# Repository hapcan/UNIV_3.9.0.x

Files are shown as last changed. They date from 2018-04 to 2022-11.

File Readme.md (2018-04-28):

UNIV 3.9.0.x
============

OPEN COLLECTOR OUTPUTS - Isolated 10 channel NPN open collector outputs with clamp diodes, 24V, 500mA per channel

Device webpage: http://hapcan.com/devices/universal/univ_3/univ_3-9-0-x/

Hardware created in Eagle PCB Software http://www.cadsoftusa.com/

Firmware created in Microchip MPLAB http://www.microchip.com/mplabide/ in assembly language

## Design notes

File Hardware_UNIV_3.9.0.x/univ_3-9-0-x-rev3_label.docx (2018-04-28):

ISOLATED OPEN

COLLECTOR OUTPUTS

10 CHANNEL
UOCMAX = 24V | | IOCMAX = 500mA
TYPE | UNIV 3.9.0.x
S/N | 00000678h
BUS BUS | hapcan.com

IZOLOWANE WYJŚCIA

OTWARTY KOLEKTOR

10 KANAŁÓW
UOCMAX = 24V | | IOCMAX = 500mA
TYP | UNIV 3.9.0.x
S/N | 00000678h
BUS BUS | hapcan.com

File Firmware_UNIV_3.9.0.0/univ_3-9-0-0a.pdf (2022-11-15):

## OPEN COLLECTOR OUTPUTS FIRMWARE

# UNIV 3.9.0.0

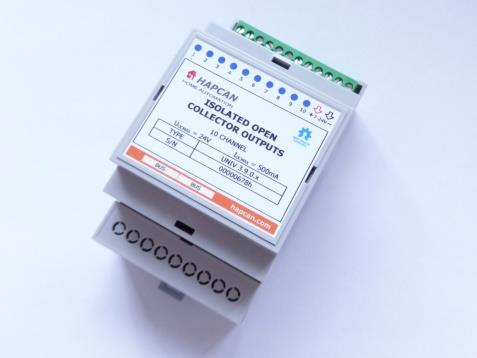
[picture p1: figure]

© 2018 hapcan.com | univ_3-9-0-0a.pdf - page 1 / 6

### 1. Features

- Firmware for 10 open collector outputs module
- 3 control instructions (on, off, toggle)
- 3 blocking instructions
- 10 timers (1 for each output) for instruction execution delay 1s-24h
- Allows defining up to 128 CAN messages which can indirectly control the module
- Settable output power up state
- Uptime counter
- Health check monitor
- Transmit (42 messages) and receive (42 messages) FIFO buffers

### 2. Compatibility

- Firmware for UNIV 3.9.0.x module
- Firmware can be uploaded into processor with bootloader version 3.1 or compatible.

### 3. Firmware version

UNIV | 3 | . | 9 | . | 0 | . | 0
firmware version
application version
application (open collector outputs) processor version
universal processor

### 4. Communication Frames (messages)

### 4.1. Open collector output message

The module sends one message to the bus for each channel as soon as the status of one of the outputs changes. The following table shows the meaning of individual bytes in the frame.

Table 1. OC output frame (0x309)
Frame type | Flags | Module | Group | D0 | D1 | D2 | D3 | D4 | D5 | D6 | D7
0x309 | 3 | 2 | 1 | 0 | Node Nr | Group Nr | 0xFF | 0xFF | CHANNEL | STATUS | 0xFF | INSTR1 | 0xFF | TIMER
0x309 | – universal module frame, OC output
3 | - | - not used flag, read as “0”
2 | - | - not used flag, read as “0”
1 | - | - not used flag, read as “0”
0 | RE | - response flag, flag is equal “1” if node was requested. If flag is equal „0” it means that status of output has just changed.
Node Nr | - message sender node number
Group Nr | - message sender group number
CHANNEL | - output channel
STATUS | - actual status of outputs 0x00 – output off, 0xFF – output on
INSTR1 | - instruction that is waiting for execution, or 0xFF if none instruction
TIMER | - delay value of waiting instruction, or 0x00 if none waiting

### 4.2. Status request

Status of module can be checked by sending from computer STATUS REQUEST frame (0x109) (Table 2).

Table 2. STATUS REQUEST frame (0x109).
Frame type | Flags | Module | Group | D0 | D1 | D2 | D3 | D4 | D5 | D6 | D7
0x109 | 0x0 | COMP ID1 | COMP ID2 | 0xXX | 0xXX | Node Nr | Group Nr | 0xXX | 0xXX | 0xXX | 0xXX
0x1090 | – STATUS REQUEST frame
COMP ID1 | - computer identifier (must be unique on the network)
COMP ID2 | - computer identifier (must be unique on the network)
Node Nr | - node number of requested module
Group Nr | - group number of requested module
0xXX | - inessential data

As response the module will send OC output frames. The meaning of bytes is the same as in Table 1.

Table 3. Response to STATUS REQUEST
Frame type | Flags | Module | Group | D0 | D1 | D2 | D3 | D4 | D5 | D6 | D7
0x309 | 0x1 | Node Nr | Group Nr | 0xFF | 0xFF | 0x01 | STATUS | 0xFF | INSTR1 | 0xFF | TIMER1
Frame type | Flags | Module | Group | D0 | D1 | D2 | D3 | D4 | D5 | D6 | D7
0x309 | 0x1 | Node Nr | Group Nr | 0xFF | 0xFF | 0x02 | STATUS | 0xFF | INSTR1 | 0xFF | TIMER2
Frame type | Flags | Module | Group | D0 | D1 | D2 | D3 | D4 | D5 | D6 | D7
0x309 | 0x1 | Node Nr | Group Nr | 0xFF | 0xFF | 0x03 | STATUS | 0xFF | INSTR1 | 0xFF | TIMER3
Frame type | Flags | Module | Group | D0 | D1 | D2 | D3 | D4 | D5 | D6 | D7
0x309 | 0x1 | Node Nr | Group Nr | 0xFF | 0xFF | 0x04 | STATUS | 0xFF | INSTR1 | 0xFF | TIMER4
Frame type | Flags | Module | Group | D0 | D1 | D2 | D3 | D4 | D5 | D6 | D7
0x309 | 0x1 | Node Nr | Group Nr | 0xFF | 0xFF | 0x05 | STATUS | 0xFF | INSTR1 | 0xFF | TIMER5
Frame type | Flags | Module | Group | D0 | D1 | D2 | D3 | D4 | D5 | D6 | D7
0x309 | 0x1 | Node Nr | Group Nr | 0xFF | 0xFF | 0x06 | STATUS | 0xFF | INSTR1 | 0xFF | TIMER6
Frame type | Flags | Module | Group | D0 | D1 | D2 | D3 | D4 | D5 | D6 | D7
0x309 | 0x1 | Node Nr | Group Nr | 0xFF | 0xFF | 0x07 | STATUS | 0xFF | INSTR1 | 0xFF | TIMER7
Frame type | Flags | Module | Group | D0 | D1 | D2 | D3 | D4 | D5 | D6 | D7
0x309 | 0x1 | Node Nr | Group Nr | 0xFF | 0xFF | 0x08 | STATUS | 0xFF | INSTR1 | 0xFF | TIMER8
Frame type | Flags | Module | Group | D0 | D1 | D2 | D3 | D4 | D5 | D6 | D7
0x309 | 0x1 | Node Nr | Group Nr | 0xFF | 0xFF | 0x09 | STATUS | 0xFF | INSTR1 | 0xFF | TIMER9
Frame type | Flags | Module | Group | D0 | D1 | D2 | D3 | D4 | D5 | D6 | D7
0x309 | 0x1 | Node Nr | Group Nr | 0xFF | 0xFF | 0x0A | STATUS | 0xFF | INSTR1 | 0xFF | TIMER10

### 4.3. Uptime request

Table 4. UPTIME REQUEST (0x113).
Frame type | Flags | Module | Group | D0 | D1 | D2 | D3 | D4 | D5 | D6 | D7
0x113 | 0x0 | COMP ID1 | COMP ID2 | 0xXX | 0xXX | Node Nr | Group Nr | 0xXX | 0xXX | 0xXX | 0xXX
0x1130 | – UPTIME REQUEST frame
COMP ID1 | - computer identifier (must be unique on the network)
COMP ID2 | - computer identifier (must be unique on the network)
Node Nr | - node number of requested module
Group Nr | - group number of requested module
0xXX | - inessential data

Table 5. Response to UPTIME REQUEST (0x113).
Frame type | Flags | Module | Group | D0 | D1 | D2 | D3 | D4 | D5 | D6 | D7
0x113 | 0x1 | Node Nr | Group Nr | 0xFF | 0xFF | 0xFF | 0xFF | UPTIME3 | UPTIME2 | UPTIME1 | UPTIME0
0x1131 | – Response to UPTIME REQUEST frame
Node Nr | - node number on the network
Group Nr | - group number of the node on the network
UPTIME | - (UPTIME3*256³+UPTIME2*256²+UPTIME1*256¹+UPTIME3*256⁰
) in seconds

### 4.4. Health check request

Table 6. HEALTH CHECK - STATUS REQUEST (0x115).
Frame type | Flags | Module | Group | D0 | D1 | D2 | D3 | D4 | D5 | D6 | D7
0x115 | 0x0 | COMP ID1 | COMP ID2 | 0x01 | 0xXX | Node Nr | Group Nr | 0xXX | 0xXX | 0xXX | 0xXX
0x1150 | – HEALTH CHECK REQUEST frame
COMP ID1 | - computer identifier (must be unique on the network)
COMP ID2 | - computer identifier (must be unique on the network)
0x01 | - status request
Node Nr | - node number of requested module
Group Nr | - group number of requested module
0xXX | - inessential data

As response the module will send two frames (Table 7).

Table 7. Response to HEALTH CHECK - STATUS REQUEST (0x115).
Frame type | Flags | Module | Group | D0 | D1 | D2 | D3 | D4 | D5 | D6 | D7
0x115 | 0x1 | Node Nr | Group Nr | 0x01 | RXCNT | TXCNT | RXCNTMX | TXCNTMX | CANINTCNT | RXERRCNT | TXERRCNT
0x1151 | – Response to HEALTH CHECK REQUEST frame
Node Nr | - node number on the network
Group Nr | - group number of the node on the network
0x01 | - frame 1 (current values)
RXCNT | - current level of receive FIFO buffer
TXCNT | - current level of transmit FIFO buffer
RXCNTMX | - maximum level of receive FIFO buffer since power up
TXCNTMX | - maximum level of transmit FIFO buffer since power up
CANINTCNT | - number of CAN interface restarts since power up
RXERRCNT | - current receive errors register
TXERRCNT | - current transmit errors register
Frame type | Flags | Module | Group | D0 | D1 | D2 | D3 | D4 | D5 | D6 | D7
0x115 | 0x1 | Node Nr | Group Nr | 0x02 | 0xFF | 0xFF | RXCNTMXE | TXCNTMXE | CANINTCNTE | RXERRCNTE | TXERRCNTE
0x1151 | – Response to HEALTH CHECK REQUEST frame
Node Nr | - node number on the network
Group Nr | - group number of the node on the network
0x02 | - frame 2 (maximum values saved in eeprom memory)
RXCNTMXE | - maximum ever level of receive FIFO buffer
TXCNTMXE | - maximum ever level of transmit FIFO buffer
CANINTCNTE | - maximum ever number of CAN interface restarts
RXERRCNTE | - maximum ever receive errors
TXERRCNTE | - maximum ever transmit errors

To clear maximum values saved in eeprom memory the frame shown in Table 8 must be sent. There is no response to this message.

Table 8. HEALTH CHECK - CLEAR REQUEST (0x115).
Frame type | Flags | Module | Group | D0 | D1 | D2 | D3 | D4 | D5 | D6 | D7
0x115 | 0x0 | COMP ID1 | COMP ID2 | 0x02 | 0xXX | Node Nr | Group Nr | 0xXX | 0xXX | 0xXX | 0xXX
0x1150 | – HEALTH CHECK REQUEST frame
COMP ID1 | - computer identifier (must be unique on the network)
COMP ID2 | - computer identifier (must be unique on the network)
0x02 | - clear request
Node Nr | - node number of requested module
Group Nr | - group number of requested module
0xXX | - inessential data

### 5. Module control

The module can be controlled directly from PC, or indirectly by other modules. In both situation all instructions in the table below can be used. Blocking instructions can’t be used in direct control.

### 5.1. Control instruction

The Table 9 shows instructions, which can be executed by the module.

Table 9. Module control instructions

Instruction | Instruction Codding | Note | Control
INSTR1 | INSTR2 | INSTR3 | INSTR4 | INSTR5 | INSTR6 | INSTR7 | INSTR8
TURN OFF OUTPUT | 0x00 | CHANNEL 1 | CHANNEL 2 | TIMER | 0xXX | 0xXX | 0xXX | 0xXX | It will turn off chosen outputs, and the rest will stay unchanged. | √ | √
TURN ON OUTPUT | 0x01 | CHANNEL 1 | CHANNEL 2 | TIMER | 0xXX | 0xXX | 0xXX | 0xXX | It will turn on chosen outputs, and the rest will stay unchanged.
TOGGLE OUTPUT | 0x02 | CHANNEL 1 | CHANNEL 2 | TIMER | 0xXX | 0xXX | 0xXX | 0xXX | It will toggle chosen outputs, and the rest will stay unchanged.

Direct

Indirect

0xXX – inessential data

CHANNEL 1 | CHANNEL 2 | Note
0x01 | 0x00 | - <00000001> <00000000> - only output OC1
0x02 | 0x00 | - <00000010> <00000000> - only output OC2
0x03 | 0x00 | - <00000011> <00000000> - output OC1 & OC2
0x04 | 0x00 | - <00000100> <00000000> - only output OC3
… | …
0xFF | 0x03 | - <11111111> <00000011> - outputs OC1-OC10
CHANNEL1
bit <0> - output OC1, bit <1> - output OC2, bit <2> - output OC3, bit <3> - output OC4, bit <4> - output OC5, bit <5> - output OC6, bit <6> - output OC7, bit <7> - output OC8 CHANNEL2
bit <0> - output OC9, bit <1> - output OC10, bit <2> - unused, bit <3> - unused,
bit <4> - unused, bit <5> - unused, bit <6> - unused, bit <7> - unused
TIMER | Note
0x00 | - instruction will be executed immediately
0x01 | - instruction will be executed with 1s delay
…
0xFF | - instruction will be executed with 24h delay
ENABLE BOX | 0xDD | BoxX | BoxY | 0xXX | 0xXX | 0xXX | 0xXX | 0xXX | It enables chosen boxes – these boxes will be compared with next received message from the bus. | √
DISABLE BOX | 0xDE | BoxX | BoxY | 0xXX | 0xXX | 0xXX | 0xXX | 0xXX | It disables chosen boxes – these boxes will be passed when next message arrives from the bus. | √
TOGGLE BOX | 0xDF | BoxX | BoxY | 0xXX | 0xXX | 0xXX | 0xXX | 0xXX | It toggles boxes – enables when they are disabled and vice versa | √

0xXX – inessential data

BoxX | Note
0x00 | - from Box 1
0x01 | - from Box 2
…
0x7F | - from Box 128
BoxY | Note
0x00 | + 0 -(and not anyone else)
0x01 | + 1 -( and 1 following)
…
0x7F | +127 -( and 127 following)

### 5.2. Timer

Each channel has its own timer which can delay execution of the instruction. Delay can be chosen between 1s-24h set in TIMER register. Drawing below shows delay dependence of TIMER register.

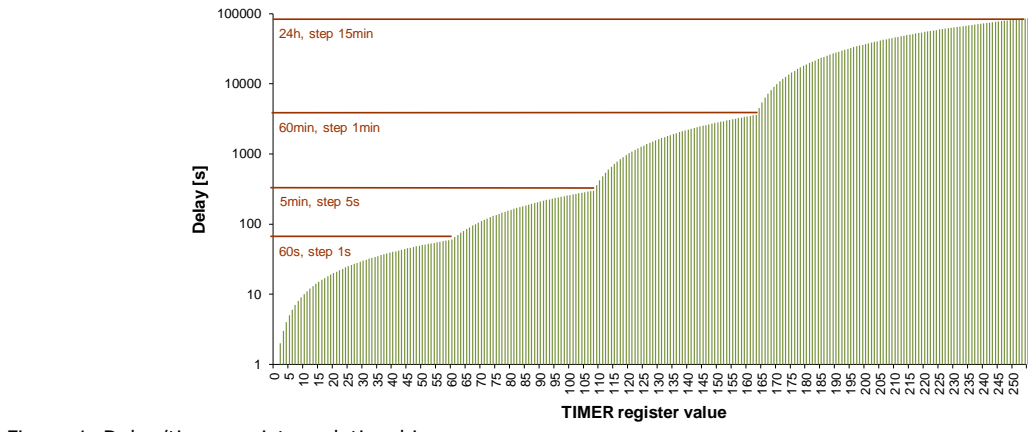
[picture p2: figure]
Delay [s]; TIMER register value; 60s, step 1s; 5min, step 5s; 60min, step 1min; 24h, step 15min

Figure 1. Delay/timer register relationship

### 5.3. Direct control

It is possible to control module by sending DIRECT CONTROL message. The message contains instruction, which will be executed by the module. The module can be also controlled from HAPCAN Programmer.

Table 10. DIRECT CONTROL frame (0x10A).
Frame type | Flags | Module | Group | D0 | D1 | D2 | D3 | D4 | D5 | D6 | D7
0x10A | 0x0 | COMP ID1 | COMP ID2 | INSTR1 | INSTR2 | Node Nr | Group Nr | INSTR3 | INSTR4 | INSTR5 | INSTR6
0x10A | – DIRECT CONTROL frame
COMP ID1 | - computer identifier (must be unique on the network)
COMP ID2 | - computer identifier (must be unique on the network)
Node Nr | - node number of requested module
Group Nr | - group number of requested module
INSTR1-6 | - instruction to be executed (byte1)

### 5.4. Indirect control

Indirect control means that module will react to messages sent by other modules on the network. It depends on configuration programmed into the module boxes (memory cells).
This firmware has feature to set simple conditions of executing instruction. To do so, you can use blocking instruction (0xDD – 0xDF) shown in Table 9.

### 6. Configuration

Below are parameters that can be configured with this firmware. Configuration process can be done using HAPCAN Programmer.

### 6.1. Module identifier

Every module on the network must have unique identifier. The identifier is made of two bytes, module number (1 byte) and group number (1 byte). Identifier of the Ethernet Interface can be changed in HAPCAN Programmer in software settings.

### 6.2. Module description

Every module can have 16 char description, which makes easier for user (programmer) to distinguish nodes.

### 6.3. Output Names

Each output can be named with 32 chars.

### 6.4. Power up values

It is possible to configure output states at startup after power loss. At startup the output can be set to ON, OFF or to the last set value. The last set value must be unchanged for at least 6s before power failure. The module sends messages to the bus about the initial state of its outputs.

6.5. Text notes.
Up to 1024 characters can be written into processor’s memory.

### 6.6. Linking devices

The indirect control is used to program the dependencies between modules. It is a controlling the module by messages sent from other modules. Each module when changing its status (eg when button is pressed or released in the button module) sends information that can be used to control the same module, as well as to control other modules located on the bus. For this purpose, the module has 128 boxes (memory cells) into which you can enter messages to which the module is to react when it receives them from the bus. Each box contains information about what message should initiate the action and what instruction should be made when this message is received.

In the figure on a side, the toggle instruction has been programmed, which changes the current state of the OC2 output at the moment of receiving a message from the module button o ID (4.1) - see the description of the BUTTON FRAME in the document "Firmware note" of the button module.

The message bytes are saved in hexadecimal format.

Operators at the front of bytes indicate that the module will react to a message received from the bus in which this byte:
x - can have any value
= - is identical to byte entered here
! - is different than byte entered here
< - is less or equal to byte entered here
> - is greater or equal to byte entered here

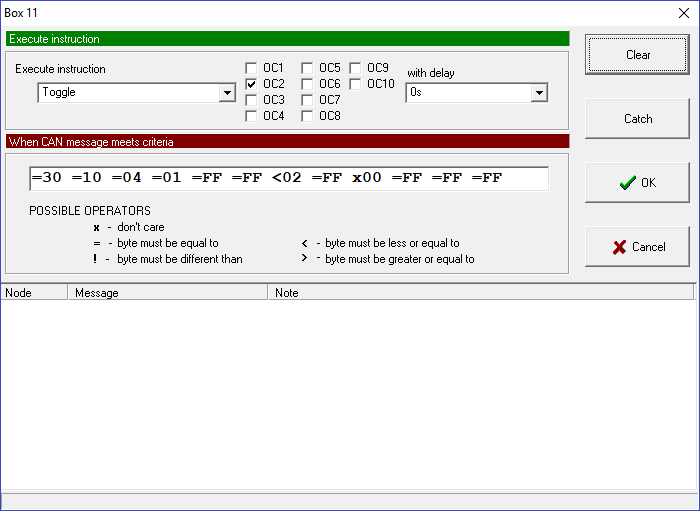
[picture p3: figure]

In this example:
=30 =10
=04 =01
=FF =FF
<02
=FF
x00

=FF =FF =FF

– button message
– module ID is (4,1)
– these bytes are not used and in button frame are always 0xFF
– button number is less or equal 2, means button number 1 or 2
– button is pressed
– it is a byte which gives LED status in the button module. Because we don’t want to make instruction execution to be depended on this byte, so this bute can have any value.
– these bytes are not used and in button frame are always 0xFF

As a result, the module will execute instructions when the module receives a message from the button with ID (4.1), when button number 1 or 2 has been pressed. Instruction is executed regardless of the LED status in the button module.

Each own and received from the bus message informing about the change of module status is checked with each active (enabled) box in the order from box no. 1 to 128. Therefore, you can set the reaction to the same message in two or more boxes. For example, in the first box instruction can be executed without delay, and in the next box another instruction can be executed after the defined time. It is important to keep the logical order of instruction executing to get the desired operation of the module. Calling an instruction that is to be executed without delay will cancel the previously set instruction with a delay.
Boxes can be dynamically activated (enabled) and deactivated (disabled). Blocking instructions are used for this (Table 9). In this way, you can control which boxes are to be checked after receiving the message.

### 7. License

HAPCAN Home Automation Project firmware, Copyright (C) 2018 hapcan.com

This program is free firmware: you can redistribute it and/or modify it under the terms of the GNU General Public License as published by the Free Software Foundation, either version 3 of the License, or (at your option) any later version.

This firmware is distributed in the hope that it will be useful, but WITHOUT ANY WARRANTY; without even the implied warranty of MERCHANTABILITY or FITNESS FOR A PARTICULAR PURPOSE. See the GNU General Public License for more details.

You should have received a copy of the GNU General Public License along with this firmware. If not, see http://www.gnu.org/licenses/gpl-3.0.html.

### 8. Document version

File | Note | Date
univ_3-9-0-0a.pdf | Initial version | March 2018

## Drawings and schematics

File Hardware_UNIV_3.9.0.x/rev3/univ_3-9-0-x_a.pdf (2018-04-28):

## OPEN COLLECTOR OUTPUTS

# UNIV 3.9.0.x

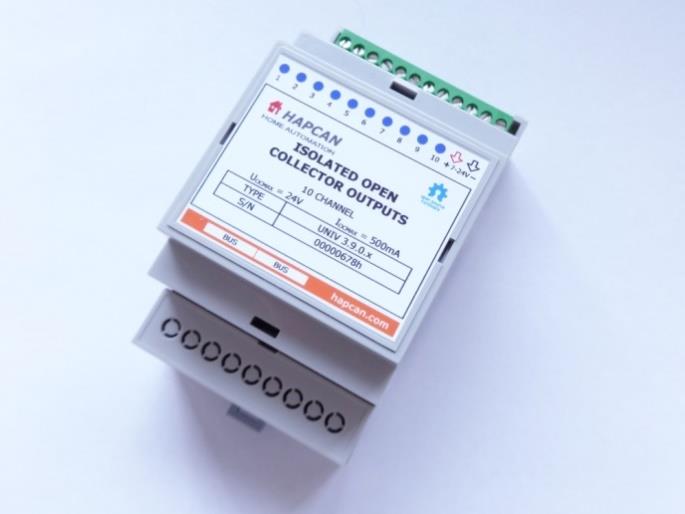
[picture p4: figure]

© 2018 hapcan.com | univ_3-9-0-x_a.pdf - page 1 / 6

### 1. Features

- Controller of 10 isolated NPN open collector outputs with clamp diodes
- Module is able to drive inductive loads (eg. relay coils) and suppress the kick-back voltage through the internal free-wheeling diodes
- Maximum collector voltage: 24V
- Maximum collector current of single transistor: 500mA
- Bus voltage: 7-24V
- Maximum current consumption from the bus
15mA@7V
- For DIN rail mounting
- Dimensions 90x58x53 mm (3 mod)
- Operating of module depends on firmware uploaded into it.
- Schematic and PCB design can be downloaded from hapcan.com site

### 2. Application version

UNIV | 3 | . | 9 | . | 0 | . | x
firmware version
application version
application type (open collector outputs) processor version
universal processor

### 3. Technical data

Bus side
Parameter | Symbol | Value | Unit
Power supply voltage | US | 7-24 | V DC
Current consumption | IS | 15@7V 6@24V | mA
Maximum current consumption (when all outputs are on) | ISMAX | 15@7V 6@24V | mA
Bus connector type | 2x RJ45

Transistors side
Parameter | Symbol | Value | Unit
Nominal power supply of transistor side | UOC | 7-24 | V DC
Nominal supply current of transistor side | IQ | 17 | mA
Maximum single transistor current | IOCMAX | 500 | mA
Insulation test voltage (1min) | UIOTM | 2500 | V AC
Connector type | Terminal Blocks (solid wire 1.5mm² , stranded 1.5mm² , stranded with ferrule 1mm² )

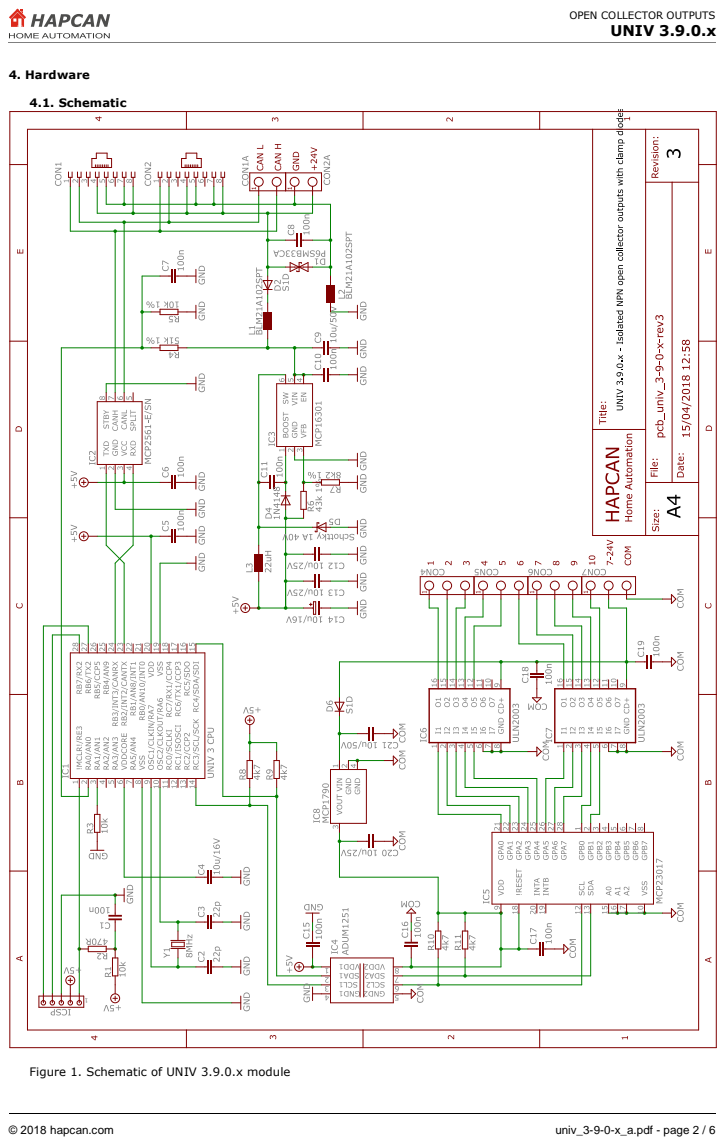
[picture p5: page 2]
4. Hardware; 4.1. Schematic

Figure 1. Schematic of UNIV 3.9.0.x module

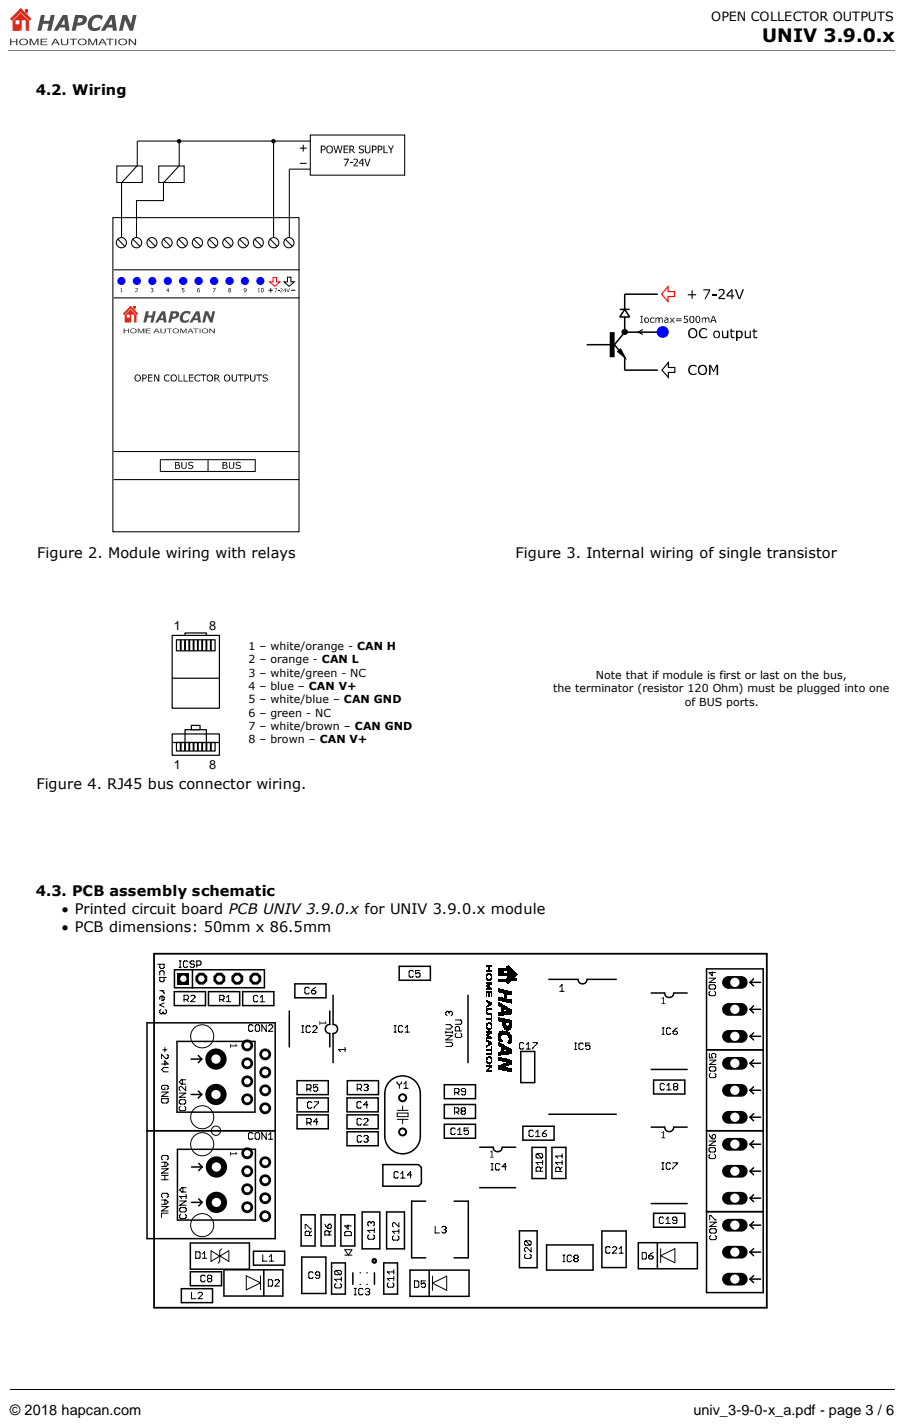
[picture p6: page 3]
4.2. Wiring; Figure 2. Module wiring with relays; Figure 3. Internal wiring of single transistor

1 – white/orange - CAN H
2 – orange - CAN L
3 – white/green - NC
4 – blue – CAN V+
5 – white/blue – CAN GND
6 – green - NC
7 – white/brown – CAN GND
8 – brown – CAN V+

Note that if module is first or last on the bus,

the terminator (resistor 120 Ohm) must be plugged into one

of BUS ports.

Figure 4. RJ45 bus connector wiring.

4.3. PCB assembly schematic
• Printed circuit board PCB UNIV 3.9.0.x for UNIV 3.9.0.x module
• PCB dimensions: 50mm x 86.5mm

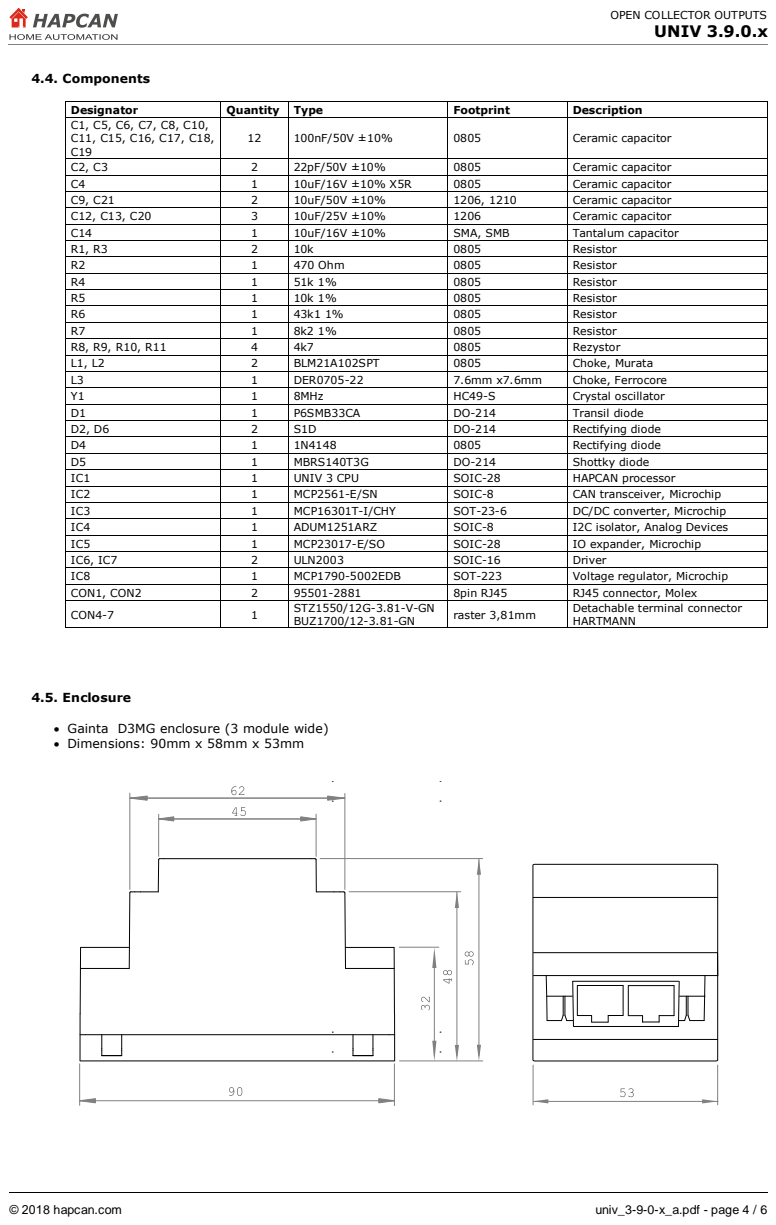
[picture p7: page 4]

Designator | Quantity | Type | Footprint | Description
C1, C5, C6, C7, C8, C10, C11, C15, C16, C17, C18, C19 | 12 | 100nF/50V ±10% | 0805 | Ceramic capacitor

C2, C3 | 2 | 22pF/50V ±10% | 0805 | Ceramic capacitor
C4 | 1 | 10uF/16V ±10% X5R | 0805 | Ceramic capacitor
C9, C21 | 2 | 10uF/50V ±10% | 1206, 1210 | Ceramic capacitor
C12, C13, C20 | 3 | 10uF/25V ±10% | 1206 | Ceramic capacitor
C14 | 1 | 10uF/16V ±10% | SMA, SMB | Tantalum capacitor
R1, R3 | 2 | 10k | 0805 | Resistor
R2 | 1 | 470 Ohm | 0805 | Resistor
R4 | 1 | 51k 1% | 0805 | Resistor
R5 | 1 | 10k 1% | 0805 | Resistor
R6 | 1 | 43k1 1% | 0805 | Resistor
R7 | 1 | 8k2 1% | 0805 | Resistor
R8, R9, R10, R11 | 4 | 4k7 | 0805 | Rezystor
L1, L2 | 2 | BLM21A102SPT | 0805 | Choke, Murata
L3 | 1 | DER0705-22 | 7.6mm x7.6mm | Choke, Ferrocore
Y1 | 1 | 8MHz | HC49-S | Crystal oscillator
D1 | 1 | P6SMB33CA | DO-214 | Transil diode
D2, D6 | 2 | S1D | DO-214 | Rectifying diode
D4 | 1 | 1N4148 | 0805 | Rectifying diode
D5 | 1 | MBRS140T3G | DO-214 | Shottky diode
IC1 | 1 | UNIV 3 CPU | SOIC-28 | HAPCAN processor
IC2 | 1 | MCP2561-E/SN | SOIC-8 | CAN transceiver, Microchip
IC3 | 1 | MCP16301T-I/CHY | SOT-23-6 | DC/DC converter, Microchip
IC4 | 1 | ADUM1251ARZ | SOIC-8 | I2C isolator, Analog Devices
IC5 | 1 | MCP23017-E/SO | SOIC-28 | IO expander, Microchip
IC6, IC7 | 2 | ULN2003 | SOIC-16 | Driver
IC8 | 1 | MCP1790-5002EDB | SOT-223 | Voltage regulator, Microchip
CON1, CON2 | 2 | 95501-2881 | 8pin RJ45 | RJ45 connector, Molex
CON4-7 | 1 | STZ1550/12G-3.81-V-GN BUZ1700/12-3.81-GN | raster 3,81mm | Detachable terminal connector HARTMANN

• Gainta D3MG enclosure (3 module wide)
• Dimensions: 90mm x 58mm x 53mm

### 4.6. Mechanical processing

Striped parts must be removed.

BODY | TERMINAL GUARDS

1x

### 4.7. Label

Editable label version is available at hapcan.com website.

ISOLATED OPEN
COLLECTOR OUTPUTS

10 CHANNEL
UOCMAX = 24V | IOCMAX = 500mA
TYPE | UNIV 3.9.0.x
S/N | 00000678h
BUS | BUS | hapcan.com

### 5. Commissioning
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

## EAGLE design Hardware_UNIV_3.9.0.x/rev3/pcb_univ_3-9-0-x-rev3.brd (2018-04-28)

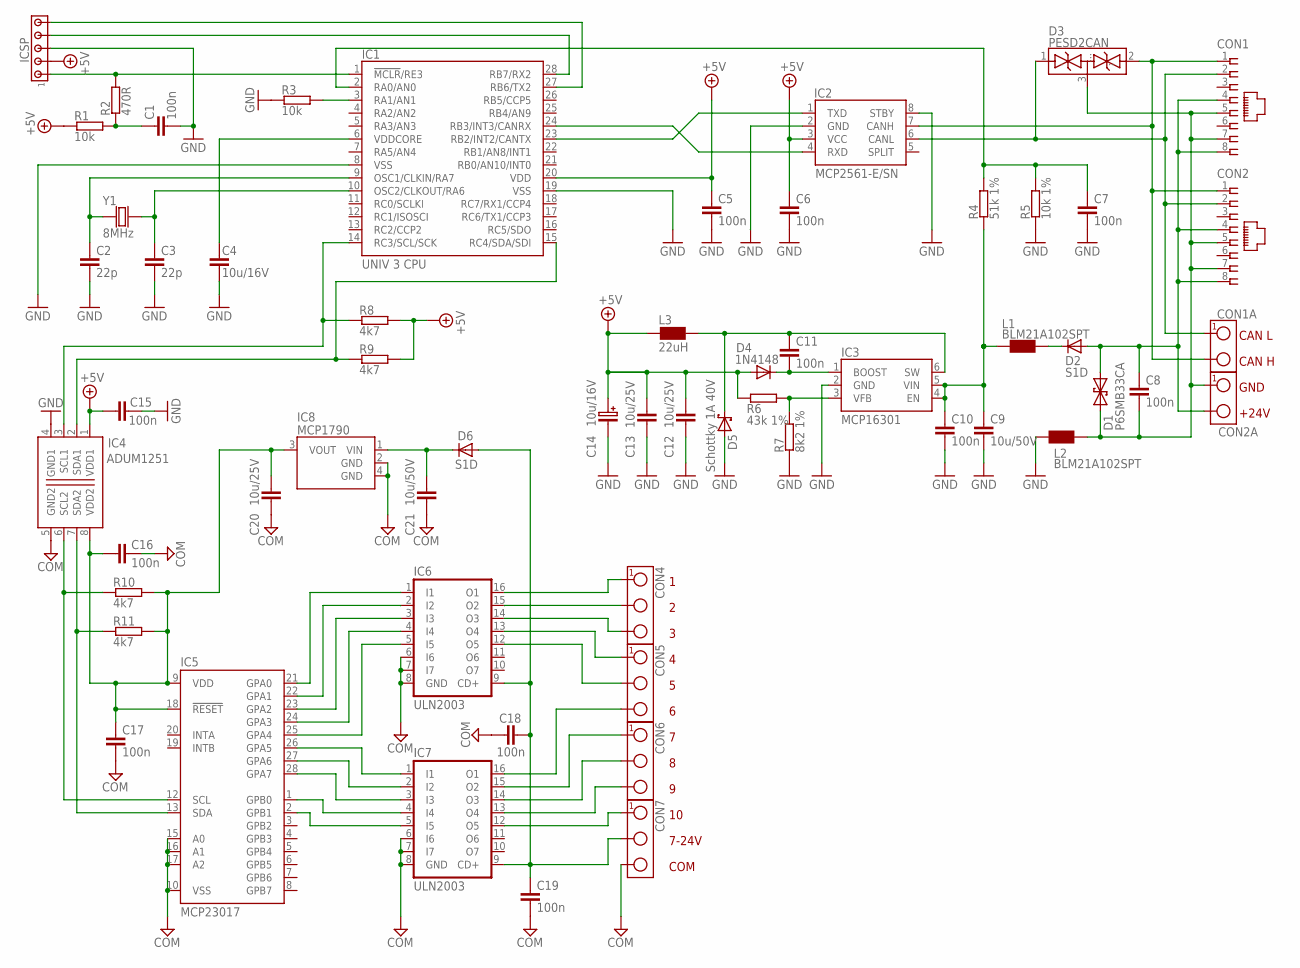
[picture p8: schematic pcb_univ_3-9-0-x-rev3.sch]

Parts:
C1, C5, C6, C7, C8, C10, C11, C15, C16, C17, C18, C19: 100n; 0805
C2, C3: 22p; 0805
C4: 10u/16V; 0805
C9, C21: 10u/50V; 1210
C12, C13, C20: 10u/25V; 1206
C14: 10u/16V; SMC_B
CON1, CON2: RJ45-SOCKET; RJ45-PCB-SOCKET
CON1A, CON2A: TERMINAL-2; ARK2-5X10,5MM
CON4, CON5, CON6, CON7: TERMINAL-3-3.81X8MM; ARK3-3.81X8MM
D1: P6SMB33CA; DO-214_TRANSIL2
D2, D6: S1D; DO-214
D3: PESD2CAN; SOT-23
D4: 1N4148; 0805
D5: Schottky 1A 40V; DO-214
IC1: UNIV 3 CPU; UNIV3CPU
IC2: MCP2561-E/SN; SO-08
IC3: MCP16301; SOT-23-6
IC4: ADUM1251; SO-08
IC5: MCP23017; SO-28W
IC6, IC7: ULN2003; SO-16
IC8: MCP1790; SOT-223
ICSP: HEADER5; SIP-5
L1, L2: BLM21A102SPT; 0805
L3: 22uH; CHOKE-DER0705
R1, R3: 10k; 0805
R2: 470R; 0805
R4: 51k 1%; 0805
R5: 10k 1%; 0805
R6: 43k 1%; 0805
R7: 8k2 1%; 0805
R8, R9, R10, R11: 4k7; 0805
Y1: 8MHz; CRYSTAL-HC49V

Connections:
+5V: C5.1, C6.1, C12.1, C13.1, C14.+ (1), C15.1, D4.2 (A), IC1.20 (VDD), IC2.3 (VCC), IC4.1 (VDD1), ICSP.2, L3.1, R1.1, R6.1, R8.2, R9.2
GND: C1.2, C2.2, C3.2, C4.2, C5.2, C6.2, C7.2, C9.2, C10.2, C12.2, C13.2, C14.- (2), C15.2, D5.A, IC1.8 (VSS), IC1.19 (VSS), IC2.2 (GND), IC2.8 (STBY), IC3.2 (GND), IC4.4 (GND1), ICSP.3, L2.1, R3.1, R5.1, R7.1
GND1: C16.2, C17.2, C18.1, C19.1, C20.2, C21.2, CON7.3, IC4.5 (GND2), IC5.10 (VSS), IC5.15 (A0), IC5.16 (A1), IC5.17 (A2), IC6.6 (I6), IC6.7 (I7), IC6.8 (GND), IC7.6 (I6), IC7.7 (I7), IC7.8 (GND), IC8.2 (GND), IC8.4 (GND)
unnamed: D2.C, L1.2
unnamed: IC1.24 (RB3/INT3/CANRX), IC2.4 (RXD)
unnamed: IC1.23 (RB2/INT2/CANTX), IC2.1 (TXD)
unnamed: CON1.1, CON1A.2, CON2.1, D3.2 (..), IC2.7 (CANH)
unnamed: C9.1, C10.1, IC3.4 (EN), IC3.5 (VIN), L1.1, R4.1
unnamed: CON4.1, IC6.16 (O1)
unnamed: C1.1, R1.2, R2.1
unnamed: IC1.1 (!MCLR!/RE3), ICSP.1, R2.2
unnamed: C8.1, CON1.4, CON1.8, CON2.4, CON2.8, CON2A.2, D1.C (2), D2.A
unnamed: IC1.28 (RB7/RX2), ICSP.4
unnamed: CON4.2, IC6.15 (O2)
unnamed: IC1.3 (RA1/AN1), R3.2
unnamed: C8.2, CON1.5, CON1.7, CON2.5, CON2.7, CON2A.1, D1.A (1), D3.3 (...), L2.2
unnamed: IC1.27 (RB6/TX2), ICSP.5
unnamed: C3.1, IC1.10 (OSC2/CLKOUT/RA6), Y1.2
unnamed: C7.1, IC1.2 (RA0/AN0), R4.2, R5.2
unnamed: C11.1, D5.C, IC3.6 (SW), L3.2
unnamed: CON4.3, IC6.14 (O3)
unnamed: CON5.1, IC6.13 (O4)
unnamed: IC3.3 (VFB), R6.2, R7.2
unnamed: CON5.2, IC6.12 (O5)
unnamed: C16.1, C17.1, C20.1, IC4.8 (VDD2), IC5.9 (VDD), IC5.18 (!RESET), IC8.3 (VOUT), R10.2, R11.2
unnamed: C21.1, D6.C, IC8.1 (VIN)
unnamed: CON5.3, IC7.16 (O1)
unnamed: CON6.1, IC7.15 (O2)
unnamed: CON1.2, CON1A.1, CON2.2, D3.1 (.), IC2.6 (CANL)
unnamed: CON6.3, IC7.13 (O4)
unnamed: CON7.1, IC7.12 (O5)
unnamed: CON6.2, IC7.14 (O3)
unnamed: C18.2, C19.2, CON7.2, D6.A, IC6.9 (CD+), IC7.9 (CD+)
unnamed: IC5.21 (GPA0), IC6.1 (I1)
unnamed: C11.2, D4.1 (C), IC3.1 (BOOST)
unnamed: IC5.22 (GPA1), IC6.2 (I2)
unnamed: C2.1, IC1.9 (OSC1/CLKIN/RA7), Y1.1
unnamed: IC5.23 (GPA2), IC6.3 (I3)
unnamed: IC5.24 (GPA3), IC6.4 (I4)
unnamed: IC5.25 (GPA4), IC6.5 (I5)
unnamed: IC5.26 (GPA5), IC7.1 (I1)
unnamed: IC5.27 (GPA6), IC7.2 (I2)
unnamed: IC5.28 (GPA7), IC7.3 (I3)
unnamed: IC5.1 (GPB0), IC7.4 (I4)
unnamed: IC5.2 (GPB1), IC7.5 (I5)
unnamed: IC4.6 (SCL2), IC5.12 (SCL), R10.1
unnamed: IC4.7 (SDA2), IC5.13 (SDA), R11.1
unnamed: C4.1, IC1.6 (VDDCORE)
unnamed: IC1.15 (RC4/SDA/SDI), IC4.2 (SDA1), R9.1
unnamed: IC1.14 (RC3/SCL/SCK), IC4.3 (SCL1), R8.1

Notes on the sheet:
CAN L
CAN H
GND
+24V
7-24V
COM

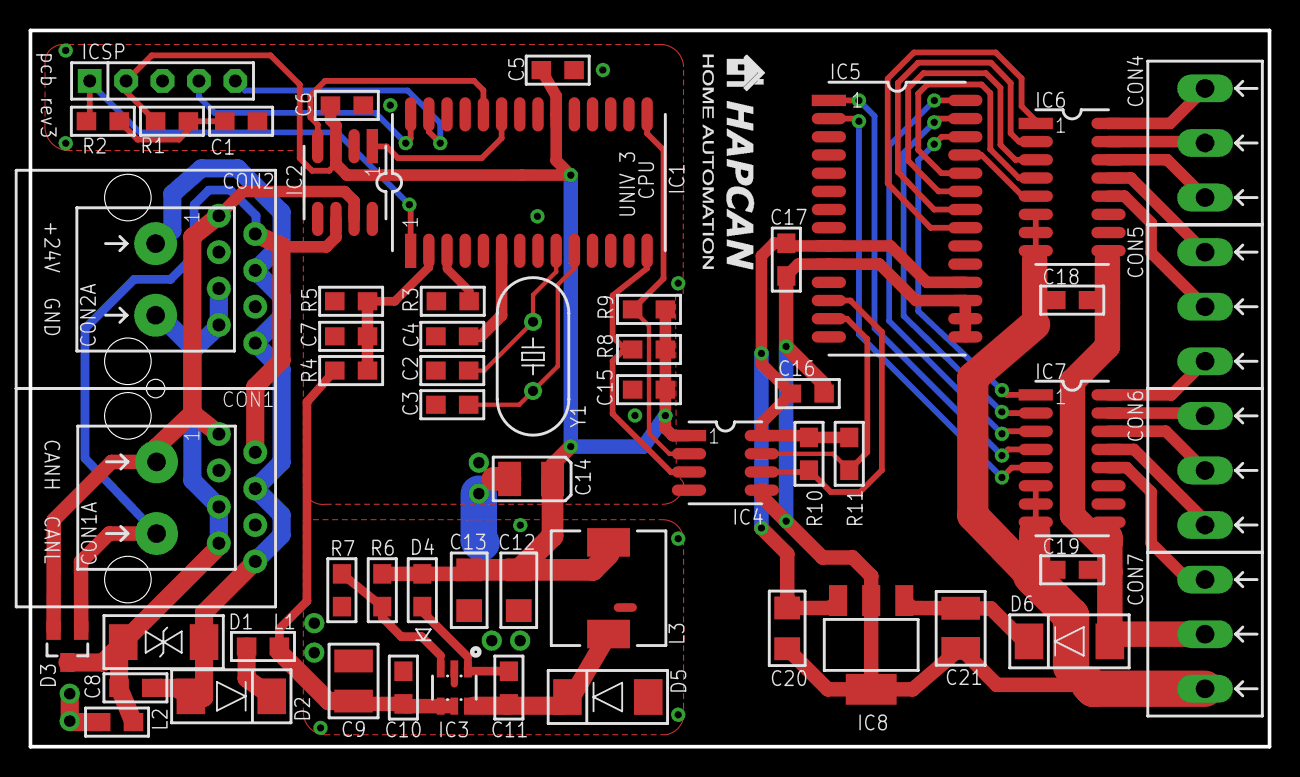
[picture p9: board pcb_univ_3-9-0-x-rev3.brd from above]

Board: 2 copper layers, 86.5 x 50.0 mm, 59 parts (0 on the bottom side), 50 nets.

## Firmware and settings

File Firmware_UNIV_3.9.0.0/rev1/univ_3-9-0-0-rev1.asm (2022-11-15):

;==============================================================================
;   MIT License
;
;   Copyright (c) 2022 HAPCAN Home Automation Project (http://hapcan.com)
;
;   Permission is hereby granted, free of charge, to any person obtaining a copy
;   of this software and associated documentation files (the "Software"), to deal
;   in the Software without restriction, including without limitation the rights
;   to use, copy, modify, merge, publish, distribute, sublicense, and/or sell
;   copies of the Software, and to permit persons to whom the Software is
;   furnished to do so, subject to the following conditions:
;
;   The above copyright notice and this permission notice shall be included in all
;   copies or substantial portions of the Software.
;
;   THE SOFTWARE IS PROVIDED "AS IS", WITHOUT WARRANTY OF ANY KIND, EXPRESS OR
;   IMPLIED, INCLUDING BUT NOT LIMITED TO THE WARRANTIES OF MERCHANTABILITY,
;   FITNESS FOR A PARTICULAR PURPOSE AND NONINFRINGEMENT. IN NO EVENT SHALL THE
;   AUTHORS OR COPYRIGHT HOLDERS BE LIABLE FOR ANY CLAIM, DAMAGES OR OTHER
;   LIABILITY, WHETHER IN AN ACTION OF CONTRACT, TORT OR OTHERWISE, ARISING FROM,
;   OUT OF OR IN CONNECTION WITH THE SOFTWARE OR THE USE OR OTHER DEALINGS IN THE
;   SOFTWARE.
;==============================================================================
;   Filename:              univ_3-9-0-0.asm
;   Associated diagram:    univ_3-9-0-x.sch
;   Author:                Jacek Siwilo                          
;   Note:                  10 Open Collector Outputs
;==============================================================================
;   Revision History
;   Rev:  Date:     Details:
;   0     06.2017   Initial version
;   1     11.2022   Updated with "univ3-routines-rev9.inc"
;==============================================================================
;===  FIRMWARE DEFINITIONS  =================================================== 
;==============================================================================
    #define    ATYPE    .9                            ;application type [0-255]
    #define    AVERS    .0                         ;application version [0-255]
    #define    FVERS    .0                            ;firmware version [0-255]

    #define    FREV     .1                         ;firmware revision [0-65536]
;==============================================================================
;===  NEEDED FILES  ===========================================================
;==============================================================================
    LIST P=18F26K80                              ;directive to define processor
    #include <P18F26K80.INC>           ;processor specific variable definitions
    #include "univ_3-9-0-0-rev1.inc"                         ;project variables
INCLUDEDFILES   code  
    #include "univ3-routines-rev9.inc"                     ;UNIV 3 CPU routines
    #include "univ3-I2C-rev1.inc"                                 ;I2C routines
;==============================================================================
;===  FIRMWARE CHECKSUM  ======================================================
;==============================================================================
FIRMCHKSM   code    0x001000
    DB      0x64, 0x52, 0xA8, 0xFF, 0xFF, 0xFF, 0xFF, 0xFF            
;==============================================================================
;===  FIRMWARE ID  ============================================================
;==============================================================================
FIRMID      code    0x001010
    DB      0x30, 0x00, 0x03,ATYPE,AVERS,FVERS,FREV>>8,FREV
;            |     |     |     |     |     |     |_____|_____ firmware revision
;            |     |     |     |     |     |__________________ firmware version
;            |     |     |     |     |_____________________ application version
;            |     |     |     |______________________________ application type
;            |     |     |________________________________ hardware version '3'
;            |_____|______________________________________ hardware type 'UNIV'
;==============================================================================
;===  MOVED VECTORS  ==========================================================
;==============================================================================
;PROGRAM RESET VECTOR
FIRMRESET   code    0x1020
        goto    Main
;PROGRAM HIGH PRIORITY INTERRUPT VECTOR
FIRMHIGHINT code    0x1030
        call    HighInterrupt
        retfie
;PROGRAM LOW PRIORITY INTERRUPT VECTOR
FIRMLOWINT  code    0x1040
        call    LowInterrupt
        retfie

;==============================================================================
;===  FIRMWARE STARTS  ========================================================
;==============================================================================
FIRMSTART   code    0x001050
;------------------------------------------------------------------------------
;---  LOW PRIORITY INTERRUPT  -------------------------------------------------
;------------------------------------------------------------------------------
LowInterrupt
        movff   STATUS,STATUS_LOW           ;save STATUS register
        movff   WREG,WREG_LOW               ;save working register
        movff   BSR,BSR_LOW                 ;save BSR register
        movff   FSR0L,FSR0L_LOW             ;save other registers used in high int
        movff   FSR0H,FSR0H_LOW
        movff   FSR1L,FSR1L_LOW
        movff   FSR1H,FSR1H_LOW

    ;main firmware ready flag
        banksel FIRMREADY
        btfss   FIRMREADY,0
        bra     ExitLowInterrupt            ;main firmware is not ready yet
    ;CAN buffer
        banksel CANFULL
        btfsc   CANFULL,0                   ;check if CAN received anything
        call    CANInterrupt                ;proceed with CAN interrupt

ExitLowInterrupt
        movff   BSR_LOW,BSR                 ;restore BSR register
        movff   WREG_LOW,WREG               ;restore working register
        movff   STATUS_LOW,STATUS           ;restore STATUS register
        movff   FSR0L_LOW,FSR0L             ;restore other registers used in high int
        movff   FSR0H_LOW,FSR0H
        movff   FSR1L_LOW,FSR1L
        movff   FSR1H_LOW,FSR1H
    return
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

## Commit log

2018-04-28 hardware UNIV 3.9.0.x revision 3
    [pcb_univ_3-9-0-x-rev3.brd, pcb_univ_3-9-0-x-rev3.sch]
2018-04-28 hardware UNIV 3.9.0.0 revision 0
    [univ_3-9-0-0-rev0-memory.xlsx]
2018-04-30 firmware UNIV 3.9.0.0 revision 0
    [univ_3-9-0-0-rev0-memory.xlsx]
2022-11-15 firmware UNIV 3.9.0.0 revision 1
    [univ_3-9-0-0-rev1-memory.xlsx]

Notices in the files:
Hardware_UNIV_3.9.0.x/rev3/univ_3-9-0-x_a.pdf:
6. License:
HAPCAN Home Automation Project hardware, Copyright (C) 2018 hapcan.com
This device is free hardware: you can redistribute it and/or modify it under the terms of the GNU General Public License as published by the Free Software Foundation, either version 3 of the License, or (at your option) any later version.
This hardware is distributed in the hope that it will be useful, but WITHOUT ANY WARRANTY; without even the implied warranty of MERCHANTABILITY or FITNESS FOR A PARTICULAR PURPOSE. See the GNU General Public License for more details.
